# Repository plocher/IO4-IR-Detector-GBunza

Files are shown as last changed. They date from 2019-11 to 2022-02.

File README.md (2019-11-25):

# IO4-IR-Detector-GBunza
## License: CERN Open Hardware Licence v1.2

IO4 Quad Optical/IR Detector baseboard

Derived from Geoff Bunza's SMA Detector, published in his column in MRH as "SMA23 – A New DCC & DC Car & Loco Detector – Differential Absolute Position Detector (DAPD)"

This version eschews "small" in favor of a remote mountable IO4 baseboard that can be mounted near the point of use, and then use [sensors disguised as ties](/pages/IO4-IR-Detector-GBunza-Fingers.html) for the sensor electronics themselves.

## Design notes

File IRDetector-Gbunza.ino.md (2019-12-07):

~~~ cpp

//
//  IR Detector 
//
//  Circuit: See the IO4-IR-Detector-GBunza board on SPCoast.com
//

#include <Wire.h>
#include <elapsedMillis.h>

//#define USE_LCD
#define DEBUG
#define HYSTERESIS 2000    // in mS units, 2000 = 2.0 seconds
#define OCCUPIED LOW
#define EMPTY    ~OCCUPIED

#ifdef USE_LCD
#define I2C_ADDR    0x27

#include <LiquidCrystal_I2C.h>
LiquidCrystal_I2C  lcd(I2C_ADDR, 16,2);
elapsedMillis updateLCDWatchdog;
#endif

#define PIN_DET1                2 // pin from IR comparator
#define PIN_DET2                3 // pin from IR comparator
#define PIN_DET3                4 // pin from IR comparator
#define PIN_DET4                5 // pin from IR comparator

#define PIN_OUT1                6 // pin to feedback connector
#define PIN_OUT2                7 // pin to feedback connector
#define PIN_OUT3                8 // pin to feedback connector
#define PIN_OUT4                9 // pin to feedback connector

#define PIN_LED1                13 // pin to LED
#define PIN_LED2                12 // pin to LED
#define PIN_LED3                11 // pin to LED
#define PIN_LED4                10 // pin to LED

#define VERSION "v1.1"  // initial version, debug LEDS and basic functionality
#define DATE    "12-06-2019" //  "6-15-2017"
#define NAME    "Quad IR Detector"

class Detector {
public:
    Detector(void) {};
    void init(int number, int det, int out, int led) {
        num = number; // which detector - for debugging
        detPin = det;
        outPin = out;
        ledPin = led;
        
        detected = false;
	active   = false;
        delaytime = 0;
        pinMode(ledPin,  OUTPUT);	// visual Feedback
        pinMode(outPin,  OUTPUT);	// digital reporting back to computer
        pinMode(detPin,  INPUT);	// input from IR detector circuit

        digitalWrite(outPin, EMPTY);    // Leave the detection pin "off"
        digitalWrite(ledPin, EMPTY);    // Leave the LED "off"
    };

    bool  isActive()   { return active == true; }
    bool  isDetected() { return detected == true; }
    
    int check(void) {
        active =  digitalRead(detPin);   // read state
        
        if (active) {           // something has been detected...
            if (detected == false) { // newly triggered
                // Serial.print("Detector ");
                // Serial.print(num, DEC);
                // Serial.print(" now ON  ");
            }
            delaytime = 0;  // expiration timer is reset every time detection is seen
            detected = true;
        }
        if (detected) {
            if (delaytime < HYSTERESIS) {
                digitalWrite(outPin, OCCUPIED); 
                digitalWrite(ledPin, OCCUPIED); 
            } else {
                // Serial.print("Detector ");
                // Serial.print(num, DEC);
                // Serial.print(" now OFF ");
                digitalWrite(outPin, EMPTY); 
                digitalWrite(ledPin, EMPTY); 
                detected = false;
            }
        }
        return detected ? 1 : 0;
    };
    
private:  
    int num;
    elapsedMillis delaytime;
    bool detected, active;
    int detPin;
    int outPin;
    int ledPin;
};

Detector circuit[4];

void setup() {

#ifdef USE_LCD
  lcd.init();               // initialize the lcd
  lcd.backlight();
  lcd.setCursor(0, 0); lcd.print(NAME);
  lcd.setCursor(0, 1); lcd.print(DATE); lcd.print(VERSION);
  updateLCDWatchdog = 0;
#endif

  circuit[0].init(1,PIN_DET1, PIN_OUT1, PIN_LED1);
  circuit[1].init(2,PIN_DET2, PIN_OUT2, PIN_LED2);
  circuit[2].init(3,PIN_DET3, PIN_OUT3, PIN_LED3);
  circuit[3].init(4,PIN_DET4, PIN_OUT4, PIN_LED4);

  delay(1000);

#ifdef USE_LCD
  lcd.clear();
#endif
}

void loop() {
    for (int x = 0; x < 4; x++) {
        circuit[x].check();
    }
#ifdef USE_LCD
    if (updateLCDWatchdog > 100) { 
        updateLCDWatchdog = 0;

    lcd.setCursor(0, 0);
    lcd.print("T1: "); lcd.print(circuit[0].isActive() ? "A" : " ");  lcd.print(circuit[0].isDetected() ? "D" : " "); 
    lcd.print("T2: "); lcd.print(circuit[1].isActive() ? "A" : " ");  lcd.print(circuit[1].isDetected() ? "D" : " "); 
    lcd.setCursor(0, 1);
    lcd.print("T3: "); lcd.print(circuit[2].isActive() ? "A" : " ");  lcd.print(circuit[2].isDetected() ? "D" : " "); 
    lcd.print("T4: "); lcd.print(circuit[3].isActive() ? "A" : " ");  lcd.print(circuit[3].isDetected() ? "D" : " "); 
    }
#else 
    delay(10);
#endif
}

~~~

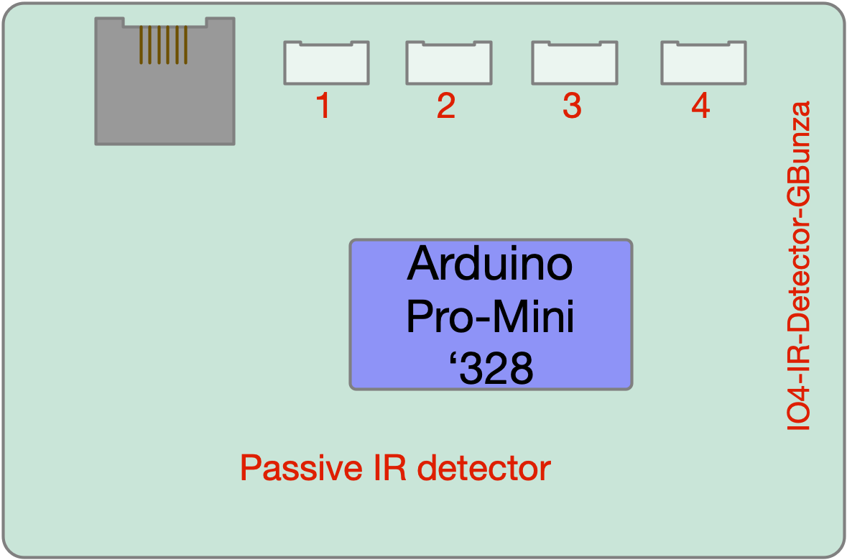
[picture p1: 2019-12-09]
IO4-IR-Detector-GBunza-Graphic.png

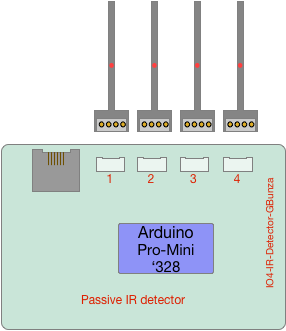
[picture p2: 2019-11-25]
IR-Detector-GBunza-Graphic.png

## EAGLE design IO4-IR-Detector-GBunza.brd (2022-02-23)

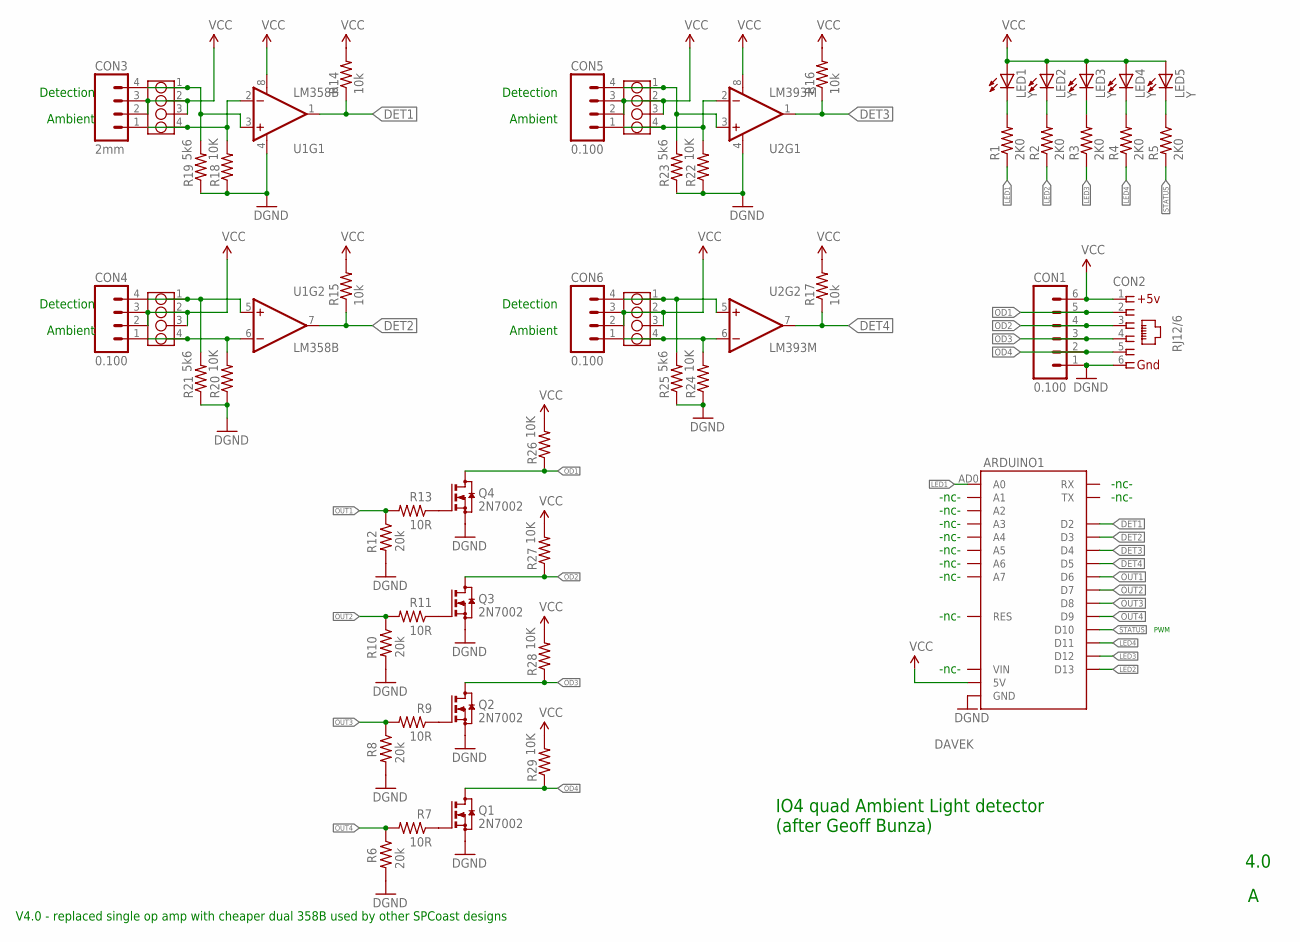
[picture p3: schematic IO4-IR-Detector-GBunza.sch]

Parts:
ARDUINO1: DAVEK; ARDUINO_PRO_MINI_DAVEK
CON1: 0.100; 1X06_LOCK
CON2: RJ12/6; RJ25-INVERTED
CON3: 2mm; 1X04_LOCK
CON4, CON5, CON6: 0.100; 1X04_LOCK
DET1, DET2, DET3, DET4: 2mm; 4P-2.0
LED1, LED2, LED3, LED4, LED5: Y; 0603-LED
Q1, Q2, Q3, Q4: 2N7002; SOT23
R1, R2, R3, R4, R5: 2K0; 0603-RES
R6, R8, R10, R12: 20k; 0603-RES
R7, R9, R11, R13: 10R; 0603-RES
R14, R15, R16, R17: 10k; 0603-RES
R18, R20, R22, R24, R26, R27, R28, R29: 10K; 0603-RES
R19, R21, R23, R25: 5k6; 0603-RES
U1: LM358B; SO08
U2: LM393M; SO08

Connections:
DET1: ARDUINO1.D2, R14.1, U1.1 (OUT)
DET2: ARDUINO1.D3, R15.1, U1.7 (OUT)
DET3: ARDUINO1.D4, R16.1, U2.1 (OUT)
DET4: ARDUINO1.D5, R17.1, U2.7 (OUT)
GND: ARDUINO1.GND@1 (GND), ARDUINO1.GND@2 (GND), ARDUINO1.GND@4 (GND), CON1.1, CON2.6, Q1.2 (S), Q2.2 (S), Q3.2 (S), Q4.2 (S), R6.2, R8.2, R10.2, R12.2, R18.1, R19.1, R20.1, R21.1, R22.1, R23.1, R24.1, R25.1, U1.4 (V-), U2.4 (V-)
LED1: ARDUINO1.AD0 (A0), R1.1
LED2: ARDUINO1.D13, R2.1
LED3: ARDUINO1.D12, R3.1
LED4: ARDUINO1.D11, R4.1
unnamed: LED5.C, R5.1
unnamed: LED4.C, R4.2
unnamed: LED3.C, R3.2
unnamed: LED2.C, R2.2
unnamed: LED1.C, R1.2
unnamed: CON3.1, DET1.4, R18.2, U1.2 (-IN)
unnamed: CON4.1, DET2.4, R20.2, U1.6 (-IN)
unnamed: CON4.4, DET2.1, R21.2, U1.5 (+IN)
unnamed: CON5.1, DET3.4, R22.2, U2.2 (-IN)
unnamed: CON5.4, DET3.1, R23.2, U2.3 (+IN)
unnamed: CON6.1, DET4.4, R24.2, U2.6 (-IN)
unnamed: CON6.4, DET4.1, R25.2, U2.5 (+IN)
unnamed: Q4.1 (G), R13.1
unnamed: CON3.4, DET1.1, R19.2, U1.3 (+IN)
unnamed: Q3.1 (G), R11.1
unnamed: Q2.1 (G), R9.1
unnamed: Q1.1 (G), R7.1
OD1: CON1.5, CON2.2, Q4.3 (D), R26.1
OD2: CON1.4, CON2.3, Q3.3 (D), R27.1
OD3: CON1.3, CON2.4, Q2.3 (D), R28.1
OD4: CON1.2, CON2.5, Q1.3 (D), R29.1
OUT1: ARDUINO1.D6, R12.1, R13.2
OUT2: ARDUINO1.D7, R10.1, R11.2
OUT3: ARDUINO1.D8, R8.1, R9.2
OUT4: ARDUINO1.D9, R6.1, R7.2
STATUS: ARDUINO1.D10, R5.2
VCC: ARDUINO1.5V, CON1.6, CON2.1, CON3.2, CON3.3, CON4.2, CON4.3, CON5.2, CON5.3, CON6.2, CON6.3, DET1.2, DET1.3, DET2.2, DET2.3, DET3.2, DET3.3, DET4.2, DET4.3, LED1.A, LED2.A, LED3.A, LED4.A, LED5.A, R14.2, R15.2, R16.2, R17.2, R26.2, R27.2, R28.2, R29.2, U1.8 (V+), U2.8 (V+)

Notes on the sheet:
IO4 quad Ambient Light detector (after Geoff Bunza)
4.0
Detection
Ambient
PWM
-nc-
V4.0 - replaced single op amp with cheaper dual 358B used by other SPCoast designs

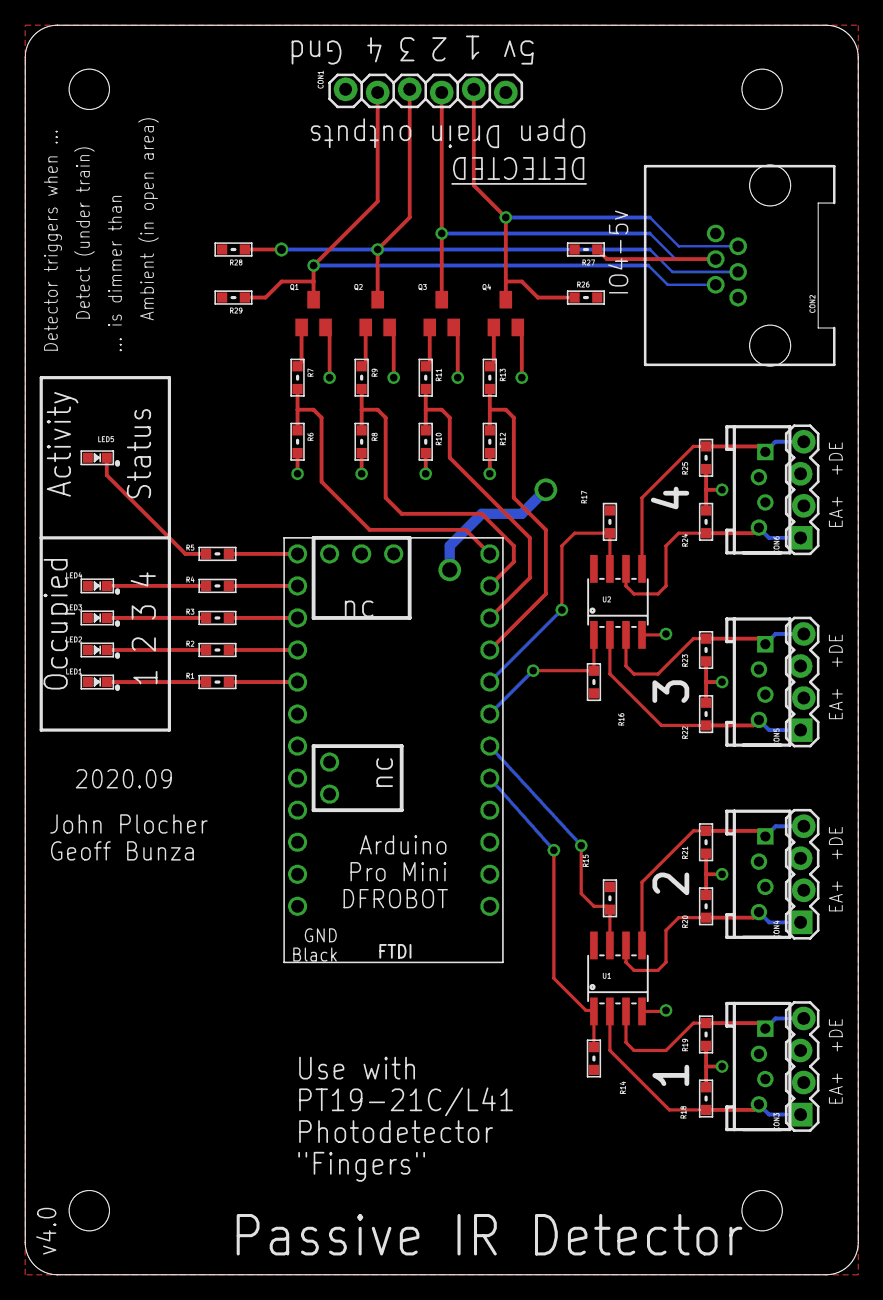
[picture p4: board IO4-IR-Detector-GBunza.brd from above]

Board: 2 copper layers, 66.0 x 99.1 mm, 51 parts (0 on the bottom side), 36 nets.

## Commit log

2020-09-23 changed from expensive TL331 to inexpensive LM258/LM358
    [IO4-IR-Detector-GBunza.brd, IO4-IR-Detector-GBunza.sch]
2020-09-24 added V4 changes note to sch
    [IO4-IR-Detector-GBunza.brd, IO4-IR-Detector-GBunza.sch]
2020-09-24 op-amp value changed to LM358B
    [IO4-IR-Detector-GBunza.brd, IO4-IR-Detector-GBunza.sch]
2020-10-06 normalized values
    [IO4-IR-Detector-GBunza.brd, IO4-IR-Detector-GBunza.sch]
2022-02-23 Vscore changed to mouse bites, larger
    [IO4-IR-Detector-GBunza.brd, IO4-IR-Detector-GBunza.sch]

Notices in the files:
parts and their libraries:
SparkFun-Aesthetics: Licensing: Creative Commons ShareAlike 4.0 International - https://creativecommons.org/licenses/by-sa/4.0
